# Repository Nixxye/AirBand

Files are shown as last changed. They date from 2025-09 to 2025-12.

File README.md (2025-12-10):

# AirBand
Os jogos musicais, embora populares, ainda dependem de periféricos específicos como guitarras e baterias, que ocupam espaço e apresentam custo elevado. Diante desse cenário, o projeto Air Band tem como objetivo desenvolver uma alternativa compacta e multifuncional: uma luva sensorizada capaz de substituir diferentes controladores tradicionais em um único dispositivo.

A luva contará com sensores de flexão e movimento, além de integração com uma webcam para captura dos gestos do usuário em tempo real. Esses dados serão processados e convertidos em comandos do jogo, possibilitando a simulação de diferentes modos (como guitarra, bateria e outros) de acordo com a configuração selecionada no software de apoio. O sistema busca oferecer praticidade, versatilidade e menor custo, sem comprometer a experiência de imersão característica dos jogos musicais.

[Cronograma](https://docs.google.com/spreadsheets/d/1t47Ufq2zki0159EHYryou9m896qojC0YicFVhhZcW6Q/edit?usp=sharing)
[Plano de projeto](imgs/PP_AirBand.pdf)
# Desenvolvimento do Projeto - Protótipo da Luva Interativa

## 09/09 - Construção do Protótipo

A primeira etapa do projeto envolve a construção do protótipo da luva, que será montada sobre uma base de MDF. A estrutura foi planejada com base no modelo 3D desenvolvido no Fusion 360, que servirá como guia para a montagem das camadas da luva.

### Etapas da Construção

A luva será formada por várias camadas, de modo que sua construção imite o modelo de exemplo que temos como referência. O objetivo é garantir precisão no design e funcionalidade do protótipo. 

Veja o modelo 3D criado no **Fusion 360**:

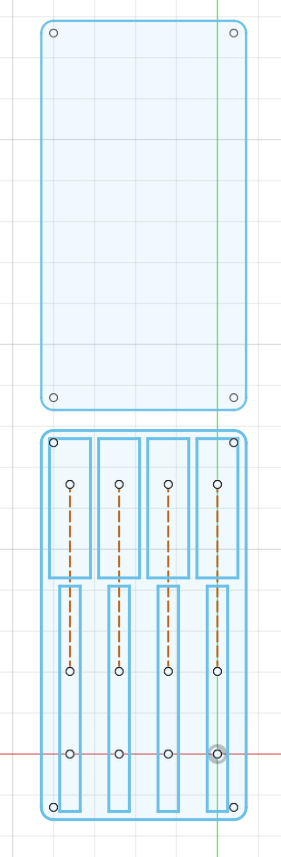
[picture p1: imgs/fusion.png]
Protótipo Fusion


### Referência do Modelo de Exemplo

A estrutura do protótipo será inspirada em um design 3D de exemplo no **Tinkercad**.

[Modelo no Tinkercad](https://www.tinkercad.com/things/4D4zS8COB8K-shiny-kup-fyyran/edit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)

## Próximos Passos

No dia **13/09**, os alunos participarão do **Workshop: Modelagem CNC para Corte a Laser**, com o objetivo de aprender as técnicas necessárias para preparar os protótipos para o corte.

---
## Densenvolvimento até 08/10

### Sensores
Testamos o funcionamento do ESP 32, do acelerômetro, do giroscópio e do potênciometro. 

### Mecânica da Luva
Após participar do Workshop, desenvolvemos e cortamos os dois modelos de MDF.
Vídeo de comparativo dos dois modelos em MDF feitos:

link: https://www.youtube.com/watch?v=WJLIjmnFiwk&feature=youtu.be

### Câmera
Testamos o reconhecimento das mãos em diferentes ambientes.

### Interface gráfica 
Inicializamos o desenvolvimento da interface gráfica. Foi feita em python.  

### Imagens adicionais
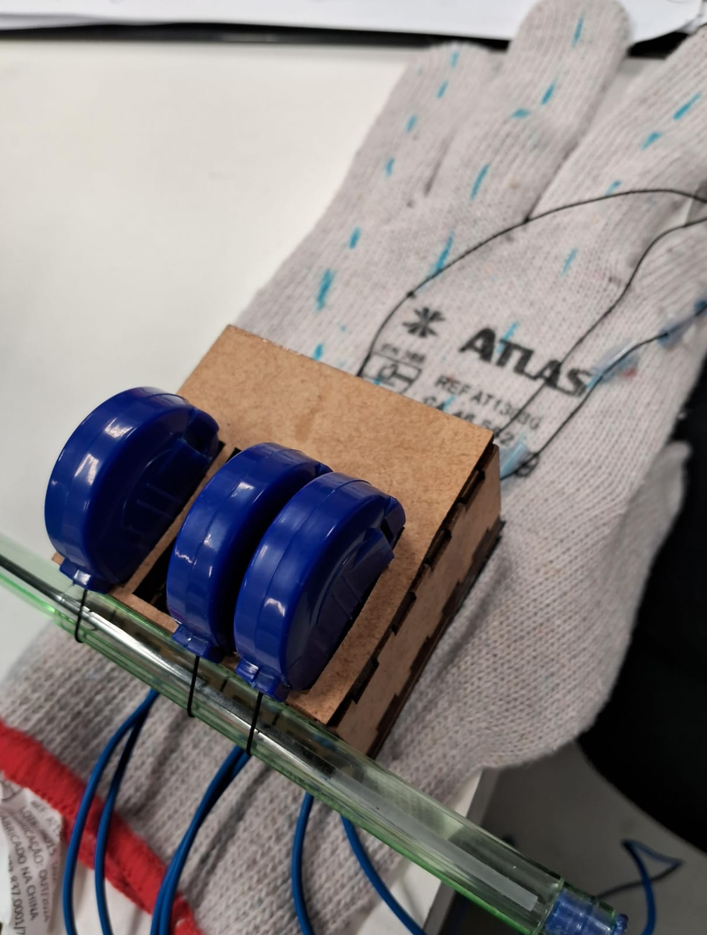
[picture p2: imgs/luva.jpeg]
Imagem da luva atual


### Próximos Passos
Agora vamos realizar a diferenciação da mão nos quadrantes usando a câmera, integrar os sensores com a interface gráfica e continuar trabalhando na mecânica da luva.

---
## Densenvolvimento até 26/11

### Sensores
Trocamos a mecânica com potenciômetros por sensores flex. Tivemos alguns problemas, pois a resposta desses sensores não era a esperada.

### Mecânica da Luva
Fixamos as ESPs com os sensores nas luvas e as fitas nos dedos utilizando velcro.

### Emulação dos controles
Desenvolvemos a parte responsável por capturar os inputs da luva e gerar os comandos de controle do jogo.

### Câmera
Fizemos a integração da parte de reconhecimento dos movimentos da câmera com a interface gráfica.

### Interface gráfica 
Finalizamos o desenvolvimento da interface gráfica, na qual o usuário calibra os sensores, escolhe o instrumento e consegue visualizar o reconhecimento dos movimentos pela câmera.

### Próximos Passos
Finalizar a integração e elaborar o relatório e o vídeo.

---
## Densenvolvimento até 08/12

### Integração e finalização
Finalizamos a integração de todas as partes da luva e elaboramos o relatório, além de gravar o vídeo.

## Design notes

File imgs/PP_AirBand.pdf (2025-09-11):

Engenharia de Computação
Oficina de Integração 2
Universidade Tecnológica Federal do Paraná (UTFPR) 2025

Prof. César M. Vargas Benítez Prof. Daniel Rossato

## Roteiro para Elaboração do Plano de Projeto (Proposta)

## 1 Título e codinome do projeto

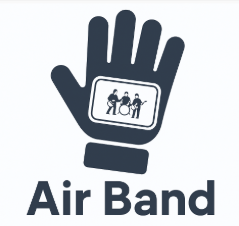
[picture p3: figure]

Air Band

## 2 Blog do projeto

Link para o blog do projeto. (https://www.notion.so/2649e0f30de7806fa761de9fb5386bd4?source=copy_link)

## 3 Equipe

- Elen Beatriz Socossiuc Souza
- Emerson Felipe da Costa Aguiar

- Isabela Helena Tulio
- Jean Carlos do Nascimento Cunha

## 4 Declaração do escopo de alto nível

Os jogos musicais, embora populares, ainda dependem de periféricos específicos como guitarras e baterias, que ocupam espaço e apresentam custo elevado. Diante desse cenário, o projeto Air Band tem como objetivo desenvolver uma alternativa compacta e multifuncional: uma luva sensorizada capaz de substituir diferentes controladores tradicionais em um único dispositivo.
A luva contará com sensores de flexão e movimento, além de integração com uma webcam para captura dos gestos do usuário em tempo real. Esses dados serão processados e convertidos em comandos do jogo, possibilitando a simulação de diferentes modos (como guitarra, bateria e outros) de acordo com a configuração selecionada no software de apoio. O sistema busca oferecer praticidade, versatilidade e menor custo, sem comprometer a experiência de imersão característica dos jogos musicais.
A arquitetura geral e a integração entre luva, webcam e software serão representadas na Figura 1, demonstrando como os componentes se comunicam para viabilizar a jogabilidade em múltiplas modalidades.

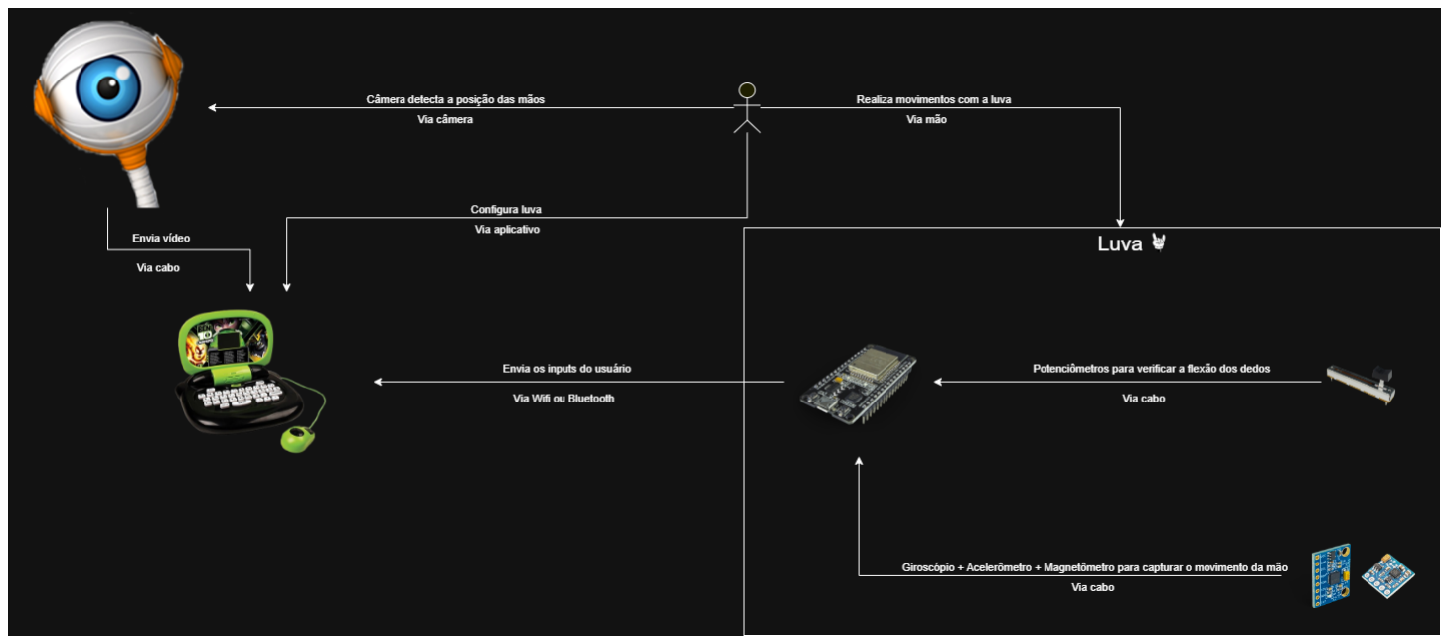
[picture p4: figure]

Figura 1: Arquitetura geral do sistema

### 4.1 Requisitos do Software

Requisitos Funcionais

- RFS01 – O software deve permitir a seleção do instrumento a ser simulado.
- RFS02 – O software deve permitir a seleção do tipo de saída, como teclado ou um joystick.
- RFS03 – O software deve oferecer uma interface gráfica intuitiva para configuração do dispositivo.
- RFS04 – O software deve possibilitar a calibração dos sensores (potenciômetros e acelerômetro) via aplicativo.
- RFS05 – O software deve suportar no mínimo dois modos de instrumento.

- RFS06 – O software deve processar em tempo real os sinais da luva e convertê-los em comandos para o jogo.
- RFS07 – O software deve registrar e exibir dados de uso para fins de depuração (ex.: intensidade do sinal, estado dos sensores).
- RFS08 – O software deve ser compatível com windows.

Requisitos Não Funcionais

- RNFS01 – O software deve apresentar baixa latência (<200 ms), de forma que o tempo de resposta seja imperceptível ao usuário.
- RNFS02 – A interface gráfica deve ser amigável, com menus organizados e responsivos.
- RNFS03 – O software deve consumir poucos recursos de hardware (CPU/RAM), permitindo execução em dispositivos de baixo custo.
- RNFS04 – O código deve ser modular e de fácil manutenção.
- RNFS05 – O sistema deve tolerar pequenos erros de leitura dos sensores sem comprometer a jogabilidade.

### 4.2 Requisitos do Hardware

Requisitos Funcionais

- RFH01 – O hardware deve detectar o movimento da mão do usuário por meio de um acelerômetro e giroscópio.
- RFH02 – O hardware deve detectar a flexão individual dos dedos por meio de potenciômetros deslizantes.
- RFH03 – O hardware deve transmitir os sinais coletados para o software em tempo real.
- RFH04 – O hardware deve utilizar um microcontrolador (ESP) como unidade de processamento principal.
- RFH05 – O hardware deve detectar, no mínimo, a flexão de quatro dedos.
- RFH06 – O hardware deve permitir comunicação sem fio entre a luva e o computador (ex.: Wi-Fi ou Bluetooth).
- RFH07 – O hardware deve possibilitar a calibração física dos sensores (reset de valores de referência).

Requisitos Não Funcionais

- RNFH01 – O hardware deve ser leve e confortável, de modo a não comprometer a jogabilidade prolongada.
- RNFH02 – Os sensores devem apresentar precisão adequada para diferenciar os níveis de flexão dos dedos.

- RNFH03 – A comunicação sem fio deve apresentar taxa de transmissão alta o suficiente (>1kbps) para evitar atrasos perceptíveis.
- RNFH04 – Os componentes devem ter custo acessível e disponibilidade no mercado nacional.
- RNFH05 – O hardware deve ser robusto o bastante para resistir ao uso contínuo.

## 5 Integração

Tabela 1: Relação entre disciplinas e conhecimentos utilizados
Disciplina | Conhecimentos Utilizados
Engenharia de Software | Levantamento dos requisitos; planejamento do de-senvolvimento do software.
Análise e Projeto de Sistemas | Elaboração de diagramas; Análise de interação software/usuário.
Fundamentos de Programação | Elaborar códigos em C/C++.
Introdução à Prática de Labora-tório em Eletricidade e Eletrônica | Soldagem de materiais eletrônicos; elaboração de esquemáticos.
Comunicação de Dados | Comunicação entre diferentes componentes.
Eletricidade / Circuitos Elétricos / Eletrônica Geral | Desenvolvimento e análise de circuitos.

## 6 Análise de riscos

Tabela 2: Matriz de riscos do projeto e estratégias de mitigação
Risco | Probabilidade (0–5) | Impacto (0–5) | Gravidade | Solução Proposta
Latência da câ-mera | 3 | 3 | 9 | Substituir por uma câ-mera de maior desem-penho
Problemas no Wi-Fi | 2 | 2 | 4 | Trocar para Bluetooth
Baixa qualidade da imagem | 2 | 3 | 6 | Usar câmera de me-lhor resolução
Demora na transmissão de dados | 1 | 3 | 3 | Trocar de protocolo
Falha nos fios do chaveiro retrátil | 2 | 2 | 4 | Usar fios mais resis-tentes ou reforçar fixa-ção
Queima do ESP | 1 | 5 | 5 | Comprar um substi-tuto
Falta de precisão dos sensores | 2 | 4 | 8 | Calibrar sensores pe-riodicamente ou subs-tituir por modelos de maior qualidade
Impossibilidade de usar o soft-ware da câmera | 2 | 4 | 8 | Avaliar alternativas de bibliotecas ou trocar o modelo de câmera
Dificuldade em integrar os sen-sores | 2 | 5 | 10 | Revisar documenta-ção, usar protocolos padrão e testar inte-gração em etapas

## 7 Cronograma detalhado

Link para o cronograma. (https://docs.google.com/spreadsheets/d/1t47Ufq2zki0159EHYryou9m896qojC0YicFVhhZcW6Q/edit?usp=sharing)

## 8 Materiais e Métodos

### 8.1 Materiais

Para o desenvolvimento da luva-controlador, serão utilizados os seguintes componentes:

- Potenciômetros deslizantes: utilizados para capturar a flexão individual dos dedos do usuário.
- Chaveiros retráteis: conectados aos potenciômetros para registrar e transmitir os movimentos dos dedos à luva.

- ESP (microcontrolador): processa os sinais recebidos dos sensores e realiza a comunicação com o software do jogo.
- Bluetooth/Wi-Fi: canais de comunicação sem fio entre a luva e o computador, garantindo transmissão em tempo real dos dados.
- Módulo giroscópio e acelerômetro: responsável por detectar a orientação e os movimentos da mão do usuário no espaço, como gestos de palhetada (guitarra) ou batidas (bateria).
- Módulo magnetômetro: utilizado para fornecer uma referência de orientação absoluta (como uma bússola), corrigindo eventuais desvios (drift) dos outros sensores de movimento e garantindo maior precisão no rastreamento a longo prazo.
- Câmera: opcional, utilizada para auxiliar no reconhecimento de gestos ou movimentos amplos da mão.
- Luva: estrutura física que serve como suporte para todos os componentes, garantindo conforto e precisão durante o uso.

Em seguida, é apresentada a tabela com quantidade e custo estimado de cada material.

Tabela 3: Materiais utilizados no projeto, quantidades e custos estimados
Quantidade | Produto | Custo Unidade | Custo Total
10 | Potenciômetros deslizantes | R$ 3,50 | R$ 35,00
10 | Chaveiros retráteis | R$ 2,50 | R$ 25,00
2 | ESP (microcontrolador) | R$ 50,00 | R$ 100,00
2 | Módulo Bluetooth/Wi-Fi | R$ 25,00 | R$ 25,00
1 | Câmera | R$ 100,00 | R$ 100,00
1 | Luva (base física) | R$ 30,00 | R$ 30,00
2 | Módulo Giroscópio e acelerômetro | R$ 30,00 | R$ 60,00
2 | Módulo Magnetômetro | R$ 35,00 | R$ 70,00

### 8.2 Métodos

- Serão elaborados diagramas de casos de uso para ilustrar a interação do usuário com a luva, detalhando os comandos e respostas do sistema.
- Serão desenvolvidos diagramas de hardware, indicando a disposição e a integração de cada componente dentro da luva.
- Diagramas de software serão criados para explicar a lógica de processamento dos sinais, calibração dos sensores e comunicação com o jogo.
- Quando necessário, serão confeccionados diagramas mecânicos, demonstrando a fixação dos potenciômetros e chaveiros retráteis na luva, garantindo precisão na detecção dos movimentos.
- A comunicação entre a luva e o software será testada via Bluetooth ou Wi-Fi, avaliando latência, confiabilidade e consistência dos dados.

- Serão realizados testes de funcionalidade, calibrando os sensores e ajustando o software para garantir que os movimentos do usuário sejam corretamente convertidos em comandos no jogo.

## Referências

[1] Benítez, César M. Vargas. Roteiro para elaboração do plano de projeto – proposta – 2022. Disponível em: http://paginapessoal.utfpr.edu.br/cesarbenitez/oficinas-de-integracao-2-eex22-1/Oficina_de_Integracao%202%20-EEX22-%20-%20roteiro%20plano%20de%20projeto%20-proposta-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. (http://paginapessoal.utfpr.edu.br/cesarbenitez/oficinas-de-integracao-2-eex22-1/Oficina_de_Integracao%202%20-EEX22-%20-%20roteiro%20plano%20de%20projeto%20-pr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) Acesso em: 1º de setembro de 2025.

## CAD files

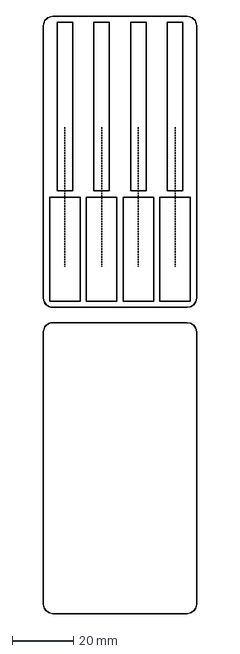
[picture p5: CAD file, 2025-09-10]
modelos/Sketch1.dxf
50.0 x 195.0 mm

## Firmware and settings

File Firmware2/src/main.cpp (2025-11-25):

#include <Arduino.h>
#include <esp_now.h>
#include <WiFi.h>
#include <Wire.h>
#include <esp_wifi.h>
#include "Gyroscope.hpp"

// --- CONFIGURAÇÃO ---
uint8_t broadcastAddress[] = {0x6C, 0xC8, 0x40, 0x8B, 0x40, 0xD1}; 

#define WIFI_CHANNEL 1

// 1. ATUALIZAÇÃO DA ESTRUTURA
// Agora contém Aceleração (ax, ay, az) + Giroscópio (gx, gy, gz)
typedef struct struct_message {
  int16_t ax; // Adicionado
  int16_t ay; // Adicionado
  int16_t az; // Adicionado
  int16_t gx;
  int16_t gy;
  int16_t gz;
} struct_message;

struct_message myData;
esp_now_peer_info_t peerInfo;
Gyroscope* gyro;

void OnDataSent(const uint8_t *mac_addr, esp_now_send_status_t status) {
  // Debug opcional
}

void setup() {
  Serial.begin(115200);
  
  gyro = Gyroscope::Init_Gyroscope();

  WiFi.mode(WIFI_STA);
  
  esp_wifi_set_promiscuous(true);
  esp_wifi_set_channel(WIFI_CHANNEL, WIFI_SECOND_CHAN_NONE);
  esp_wifi_set_promiscuous(false);

  if (esp_now_init() != ESP_OK) {
    Serial.println("Erro ao iniciar ESP-NOW");
    return;
  }
  esp_now_register_send_cb(OnDataSent);

  memcpy(peerInfo.peer_addr, broadcastAddress, 6);
  peerInfo.channel = WIFI_CHANNEL;  
  peerInfo.encrypt = false;
  
  if (esp_now_add_peer(&peerInfo) != ESP_OK){
    Serial.println("Falha ao adicionar par");
    return;
  }
  
  Serial.println("Slave Iniciado! Enviando Accel + Gyro...");
}

void loop() {
  gyro->loop(); 

  int16_t temp; // Variável temporária para temperatura (não enviada)
  
  // Passamos os endereços das variáveis da struct diretamente
  gyro->getData(
    &myData.ax, &myData.ay, &myData.az, 
    &temp, 
    &myData.gx, &myData.gy, &myData.gz
  );

  esp_err_t result = esp_now_send(broadcastAddress, (uint8_t *) &myData, sizeof(myData));
  
  delay(10);
}

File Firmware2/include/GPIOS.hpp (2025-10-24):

#ifndef GPIOS_H
#define GPIOS_H

#include "stdint.h"

// LED de status
static const uint8_t PIN_LED_STATUS = 2; 

// Botão start
static const uint8_t PIN_BUTTON = 27;


static const uint8_t PIN_I00_ESP = 0; // GPIO0

// Motores
static const uint8_t PIN_M1 = 4;
static const uint8_t PIN_M2 = 16;
static const uint8_t PIN_M3 = 13;
static const uint8_t PIN_M4 = 14;

// I2C
static const uint8_t PIN_SCK = 18;
static const uint8_t PIN_MISO = 19;
static const uint8_t PIN_SDA = 21;
static const uint8_t PIN_SCL = 22;
static const uint8_t PIN_MOSI = 23;

// Comunicação (se forem usados)
static const uint8_t PIN_TX_USB = 1;
static const uint8_t PIN_RX_USB = 3;

// Outros sinais (se usados para módulo RF ou sensores)
static const uint8_t PIN_CE  = 32;
static const uint8_t PIN_CSN = 33;
static const uint8_t PIN_INT = 34;
static const uint8_t PIN_IRQ = 35;

static const uint8_t INT_GYRO_PIN = 5; // GPIO de interrupção do giroscópio
static const uint8_t INT_MAG_PIN = 15;  // GPIO de interrupção para o Magnetômetro
#endif // GPIOS_H

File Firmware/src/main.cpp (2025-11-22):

#include <Arduino.h>
#include "Gyroscope.hpp"
#include "Magnetometer.hpp"
#include "AnalogReader.hpp"
#include "WifiServer.hpp"

Gyroscope* gyro;
Magnetometer* mag;
AnalogReader* adcReader;
WifiServer* wifi;

#define WIFI_SSID "ALuvaQueTePariu"
#define WIFI_PASSWORD "teste1234"

void setup() {
    Serial.begin(115200);
    delay(100);
    Serial.println("| MAIN | ---------- Iniciando setup --------");

    gyro = Gyroscope::Init_Gyroscope(); 
    mag = Magnetometer::Init_Magnetometer();
    adcReader = AnalogReader::Init_AnalogReader();

    wifi = WifiServer::Init_WifiServer(WIFI_SSID, WIFI_PASSWORD);

    Serial.println("| MAIN | Setup concluído.");
}

void loop() {
    gyro->loop();
    // mag->loop();
    adcReader->loop();

    wifi->loop();

    vTaskDelay(1); 
}

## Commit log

2025-08-27 Adição do código de mediapipe
2025-09-10 Adição de sketch do fusion
    [Sketch1.dxf]
2025-09-11 Adição do plano de projeto
2025-10-14 Modificando testes do mediapipe para poses
2025-10-24 Testando biblioteca para o qmc
2025-10-28 Classe para leitura analógica
2025-10-28 Testes de inputs
2025-11-12 calibração dos dedos ok, falta verificar a taxa de amostragem dos dados na luva
2025-11-21 Mudando os requisitos
    Mudei pq instalando essa versão do open cv não dá erro de conflito com o PyQt5. Tirei o qt-materials pq em algum momento tava dando conflito com ele também e eu tirei já que ele não é mt necessário.
2025-11-22 Removendo prints do giroscópio
2025-11-22 Adição de threads
2025-11-23 Ajustando para calcular limites na guitarra
2025-11-23 Adicionando logs de debug à segunda esp
2025-11-25 Adicionando gráficos para log dos sensores da luva
2025-11-25 Atualizando valores de entrada nos gráficos
2025-11-25 Fazendo o vetor de calibração ter mais pontos
2025-11-25 ajustando worker para os dados do giroscópio
2025-11-26 Mudanças na câmera - função para retornar as teclas da bateria
2025-11-27 retirando else fora de lugar
